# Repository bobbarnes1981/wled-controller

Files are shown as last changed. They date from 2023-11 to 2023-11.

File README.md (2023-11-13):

# wled-controller

A controller board for wled with the following features

* ESP32 DevKitC pin layout
* Relay switched LED supply
* 4 level shifted led outputs
* 2 buttons
* Indicator LEDs for 5v in, Relay and 5v out
* INMP441 Microphone module connection
* Mini automotive fuses

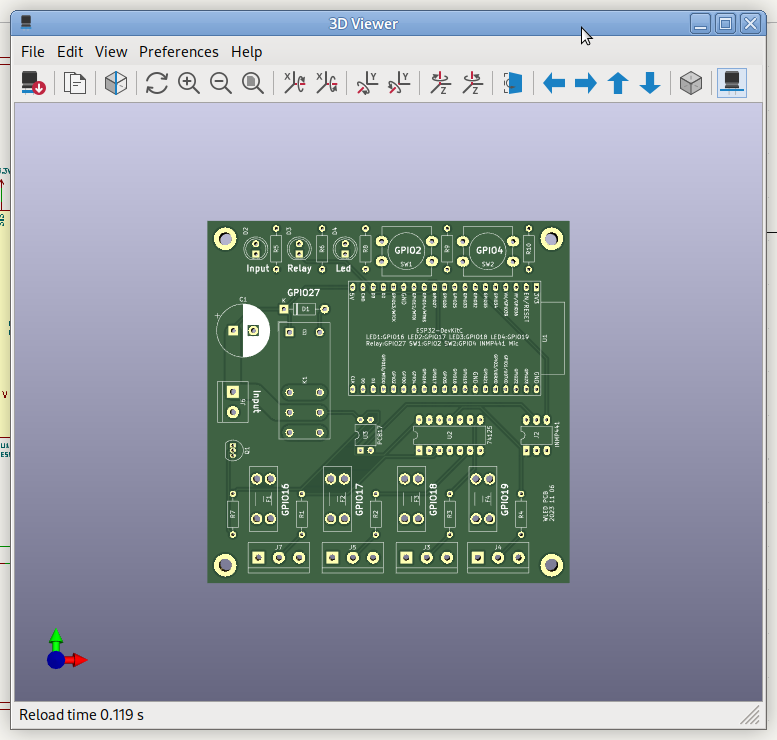
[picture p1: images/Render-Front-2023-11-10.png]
Render Front


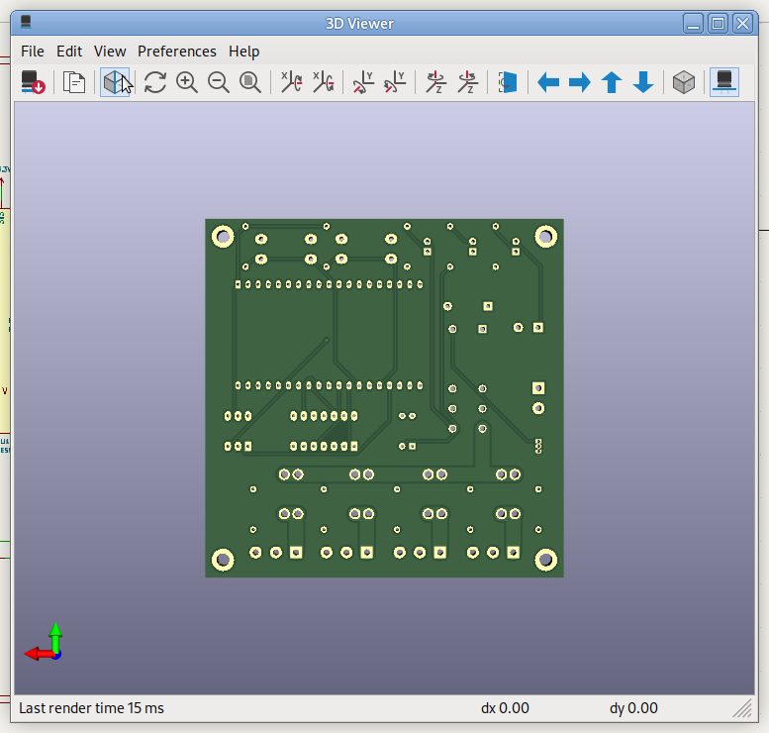
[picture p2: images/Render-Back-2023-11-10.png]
Render Back


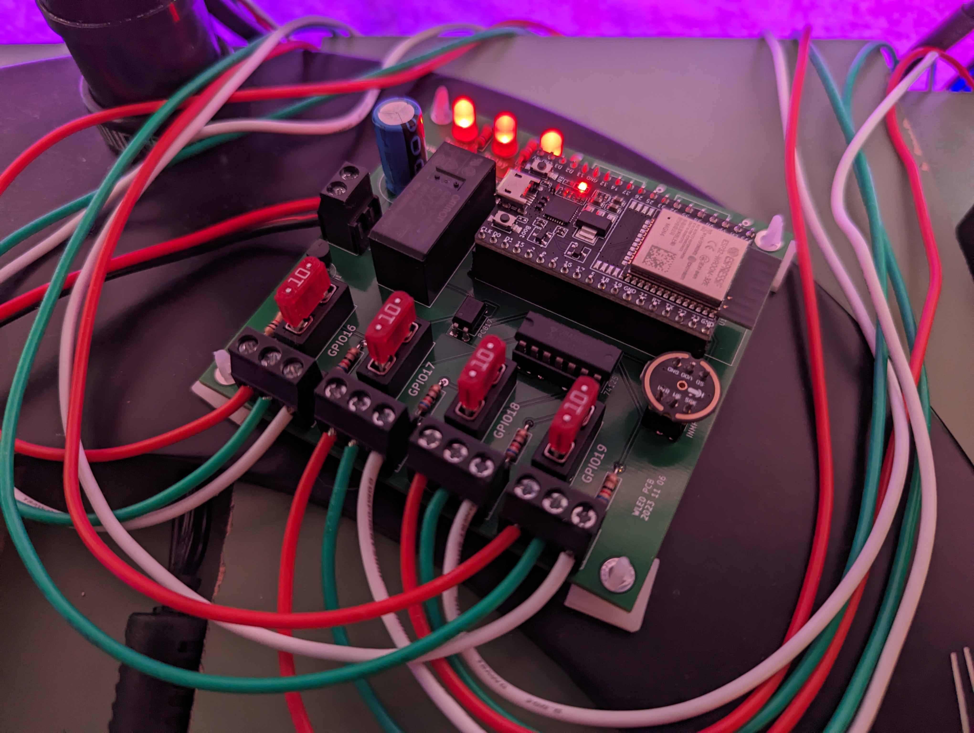
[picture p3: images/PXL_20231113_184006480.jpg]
Working


Built

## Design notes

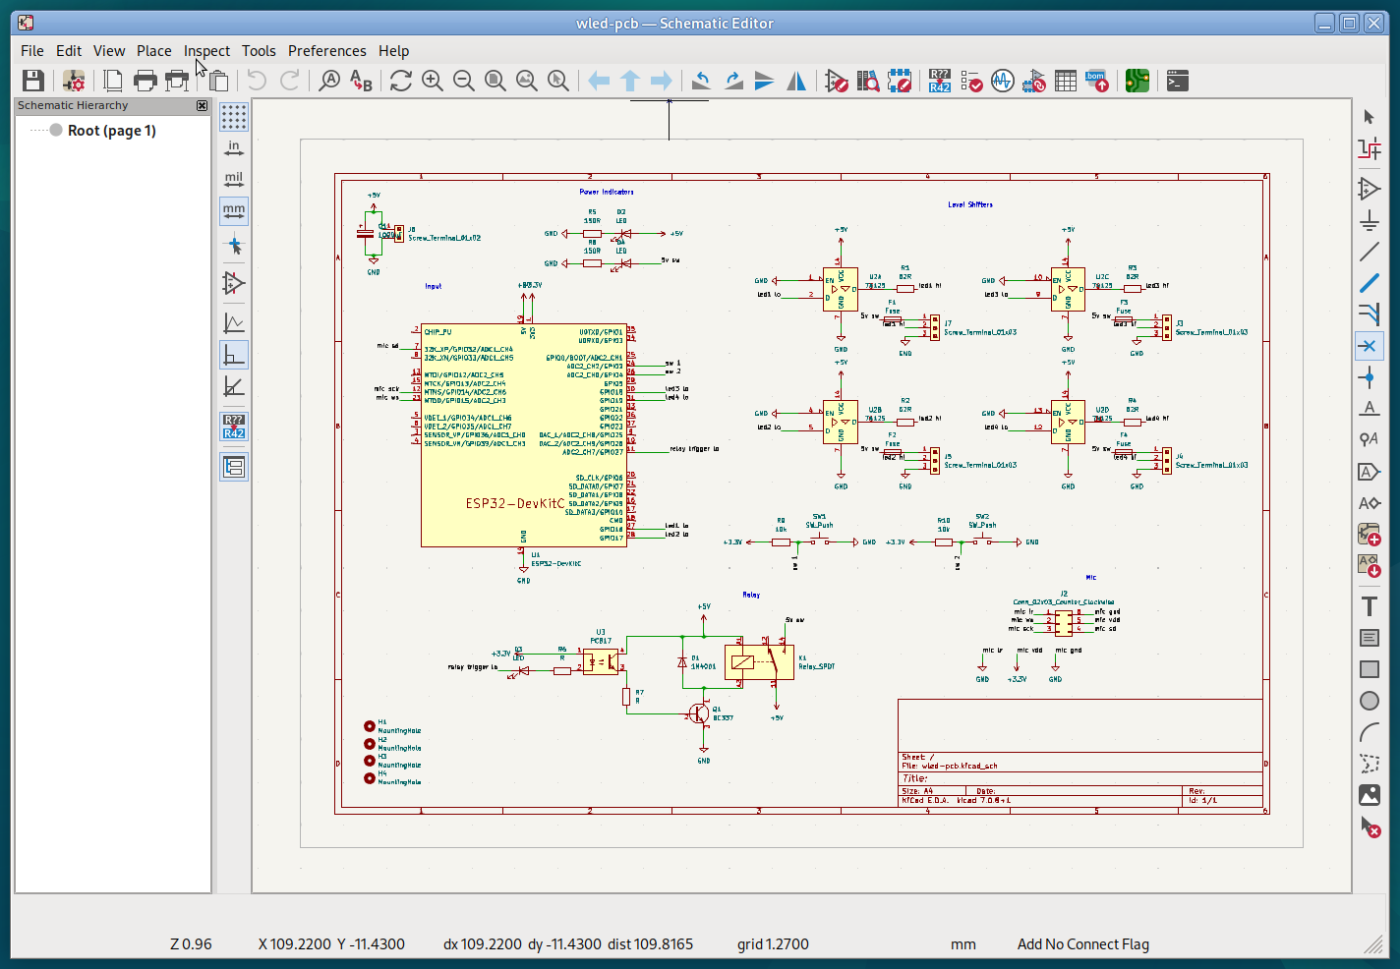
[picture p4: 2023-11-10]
images/Schematic-2023-11-10.png

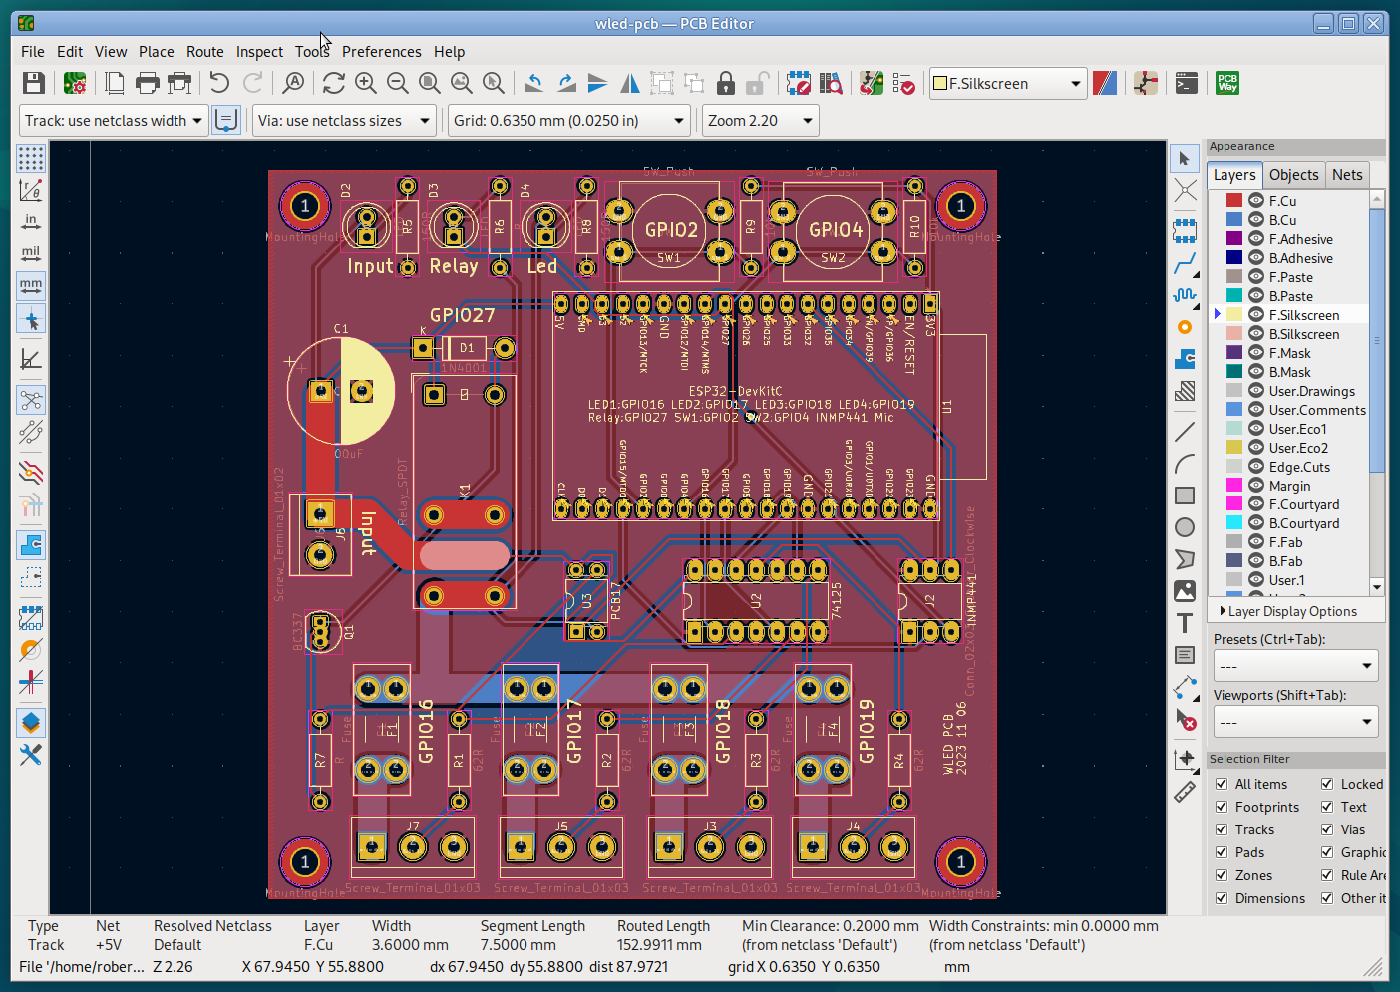
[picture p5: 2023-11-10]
images/PCB-2023-11-10.png

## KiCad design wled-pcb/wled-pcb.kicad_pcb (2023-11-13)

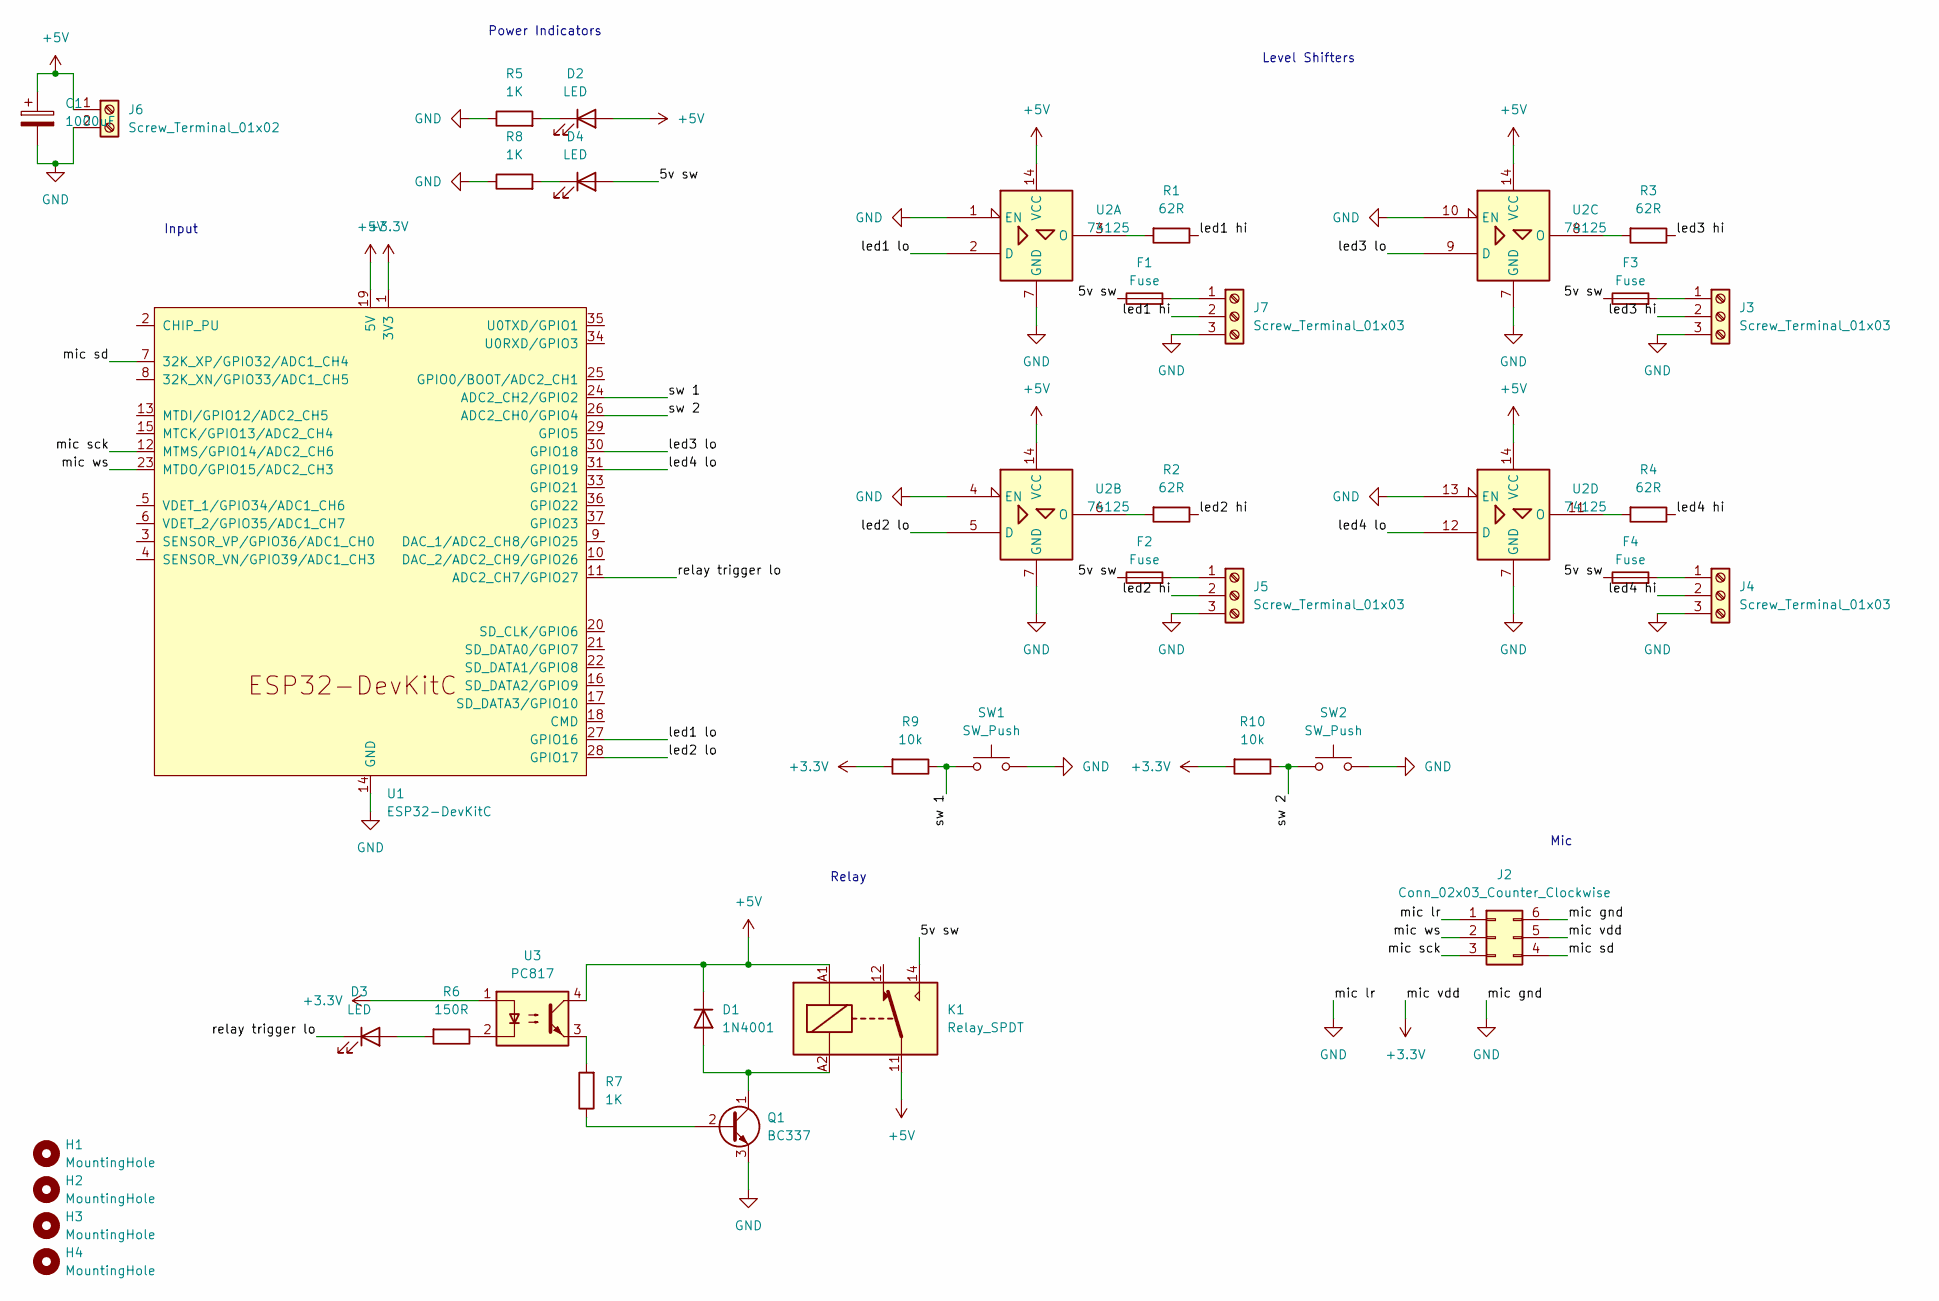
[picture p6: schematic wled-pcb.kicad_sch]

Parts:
C1: 1000uF; CP_Radial_D13.0mm_P5.00mm
D1: 1N4001; D_DO-41_SOD81_P10.16mm_Horizontal
D2, D3, D4: LED; LED_D5.0mm
F1, F2, F3, F4: Fuse; Fuseholder_Blade_Mini_Keystone_3568
H1, H2, H3, H4: MountingHole; MountingHole_3.2mm_M3_DIN965_Pad_TopBottom
J2: Conn_02x03_Counter_Clockwise; DIP-6_W7.62mm_LongPads
J3, J4, J5, J7: Screw_Terminal_01x03; TerminalBlock_bornier-3_P5.08mm
J6: Screw_Terminal_01x02; TerminalBlock_bornier-2_P5.08mm
K1: Relay_SPDT; Relay_SPDT_Omron_G2RL-1-E
Q1: BC337; TO-92_Inline
R1, R2, R3, R4: 62R; R_Axial_DIN0207_L6.3mm_D2.5mm_P10.16mm_Horizontal
R5, R7, R8: 1K; R_Axial_DIN0207_L6.3mm_D2.5mm_P10.16mm_Horizontal
R6: 150R; R_Axial_DIN0207_L6.3mm_D2.5mm_P10.16mm_Horizontal
R9, R10: 10k; R_Axial_DIN0207_L6.3mm_D2.5mm_P10.16mm_Horizontal
SW1, SW2: SW_Push; SW_PUSH-12mm_Wuerth-430476085716
U1: ESP32-DevKitC
U2: 74125; DIP-14_W7.62mm_LongPads
U3: PC817; DIP-4_W7.62mm

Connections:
+3.3V: J2.5, R9.2, R10.2, U1.1 (3V3), U3.1
+5V: C1.1, D1.1 (K), D2.2 (A), J6.1, K1.11, K1.A1, U1.19 (5V), U2.14 (VCC), U3.4
/5v sw: D4.2 (A), F1.1, F2.1, F3.1, F4.1, K1.14
/led1 hi: J7.2, R1.1
/led1 lo: U1.27 (GPIO16), U2.2 (D)
/led2 hi: J5.2, R2.1
/led2 lo: U1.28 (GPIO17), U2.5 (D)
/led3 hi: J3.2, R3.1
/led3 lo: U1.30 (GPIO18), U2.9 (D)
/led4 hi: J4.2, R4.1
/led4 lo: U1.31 (GPIO19), U2.12 (D)
/mic sck: J2.3, U1.12 (MTMS/GPIO14/ADC2_CH6)
/mic sd: J2.4, U1.7 (32K_XP/GPIO32/ADC1_CH4)
/mic ws: J2.2, U1.23 (MTDO/GPIO15/ADC2_CH3)
/relay trigger lo: D3.1 (K), U1.11 (ADC2_CH7/GPIO27)
/sw 1: R9.1, SW1.1, U1.24 (ADC2_CH2/GPIO2)
/sw 2: R10.1, SW2.1, U1.26 (ADC2_CH0/GPIO4)
GND: C1.2, J2.1, J2.6, J3.3, J4.3, J5.3, J6.2, J7.3, Q1.3 (E), R5.1, R8.1, SW1.2, SW2.2, U1.14 (GND), U1.32 (GND), U1.38 (GND), U2.1 (EN), U2.4 (EN), U2.7 (GND), U2.10 (EN), U2.13 (EN)
unnamed: D1.2 (A), K1.A2, Q1.1 (C)
unnamed: D2.1 (K), R5.2
unnamed: D3.2 (A), R6.2
unnamed: D4.1 (K), R8.2
unnamed: F3.2, J3.1
unnamed: F4.2, J4.1
unnamed: F2.2, J5.1
unnamed: F1.2, J7.1
unnamed: Q1.2 (B), R7.1
unnamed: R6.1, U3.2
unnamed: R7.2, U3.3
unnamed: R1.2, U2.3 (O)
unnamed: R2.2, U2.6 (O)
unnamed: R3.2, U2.8 (O)
unnamed: R4.2, U2.11 (O)

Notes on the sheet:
Relay
Level Shifters
Power Indicators
Input
Mic

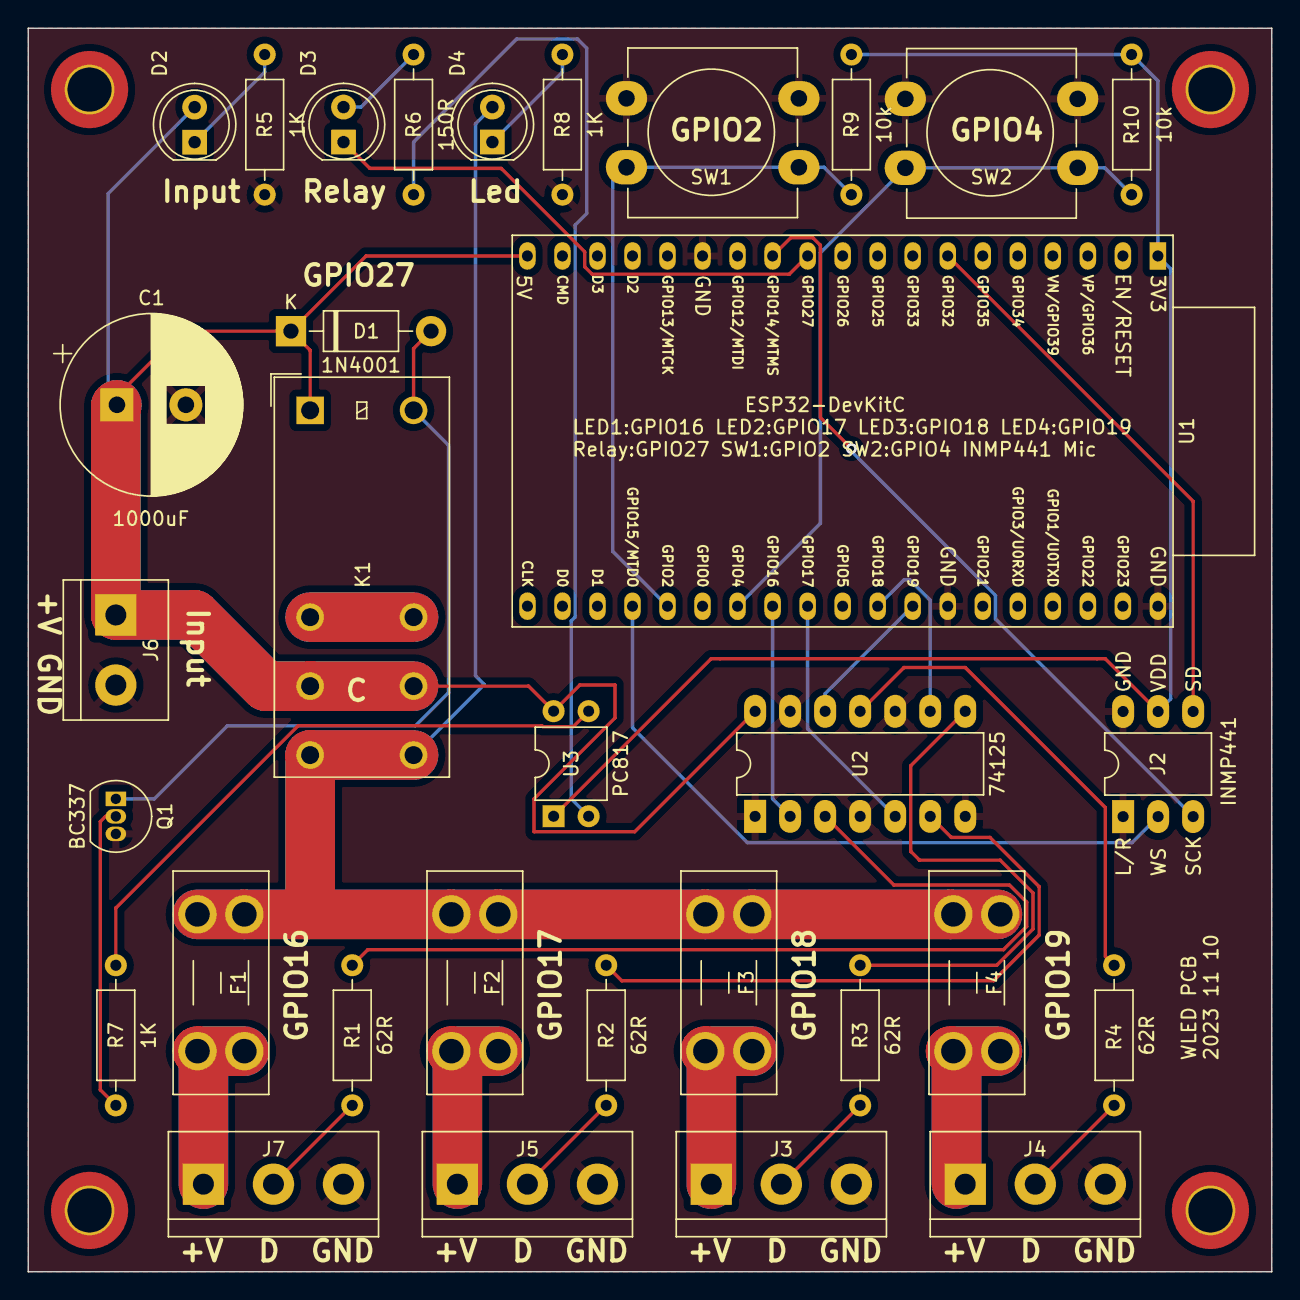
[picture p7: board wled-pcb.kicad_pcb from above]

Board: 2 copper layers, 90.2 x 90.2 mm, 36 parts (0 on the bottom side), 33 nets.

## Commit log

2023-11-05 add footprints
    [wled-pcb.kicad_pcb, wled-pcb.kicad_sch]
2023-11-05 add footprints to pcb
    [wled-pcb.kicad_pcb, wled-pcb.kicad_sch]
2023-11-05 fix some mistakes, route some traces
    [wled-pcb.kicad_pcb, wled-pcb.kicad_sch]
2023-11-05 Add buttons, route tracks
    [wled-pcb.kicad_pcb, wled-pcb.kicad_sch]
2023-11-06 layout board smaller than 100x100
    [wled-pcb.kicad_pcb, wled-pcb.kicad_sch]
2023-11-06 route tracks
    [wled-pcb.kicad_pcb]
2023-11-06 generate gerbers
    [wled-pcb-B_Cu.gbl, wled-pcb-B_Mask.gbs, wled-pcb-B_Paste.gbp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]
2023-11-06 remove gerbers
    [wled-pcb-B_Cu.gbl, wled-pcb-B_Mask.gbs, wled-pcb-B_Paste.gbp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]
2023-11-06 use different pins for switches
    [wled-pcb.kicad_pcb, wled-pcb.kicad_sch]
2023-11-06 kicad plugin
2023-11-06 pcbway files
2023-11-06 3.6mm trace should give 6A@1oz and 10A@2oz
    [wled-pcb.kicad_pcb]
2023-11-10 Rotate spokes to pass DRC
    [wled-pcb.kicad_pcb]
2023-11-10 Duplicate power traces on both sides of PCB
    [wled-pcb.kicad_pcb]
2023-11-10 Add connector text
    [wled-pcb.kicad_pcb]
2023-11-13 Add more info to silkscreen
    [wled-pcb.kicad_pcb, wled-pcb.kicad_sch]
